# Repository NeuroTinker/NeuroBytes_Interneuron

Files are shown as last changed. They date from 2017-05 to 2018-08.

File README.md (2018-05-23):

# NeuroBytes Interneuron
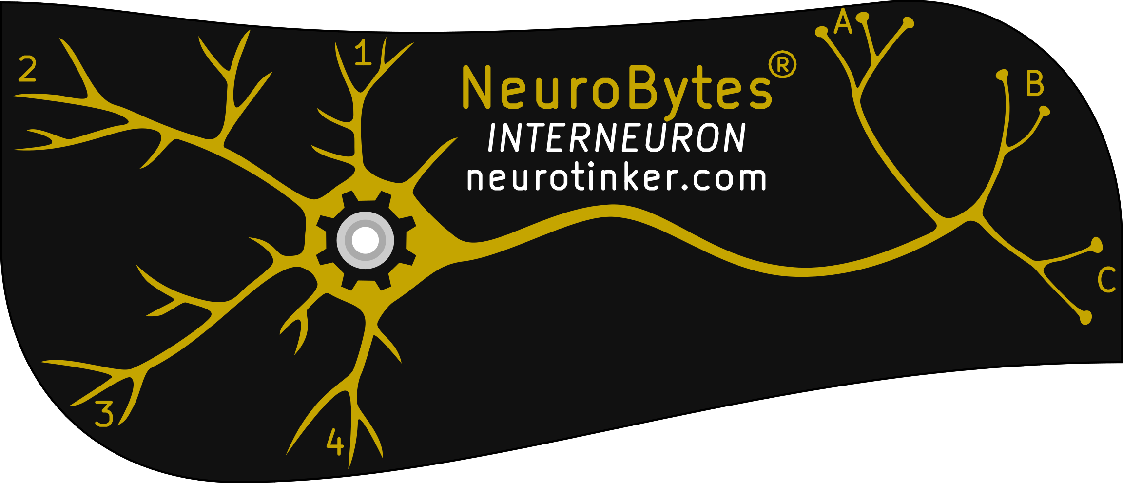
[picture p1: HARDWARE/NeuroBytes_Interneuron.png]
NeuroBytes Interneuron PCB front

The Interneuron is an open-source hardware neuron simulator designed and sold by [NeuroTinker, LLC](http://www.neurotinker.com/). Each device includes a number of inputs (dendrites) and outputs (the axon terminal) that can be freely connected to other NeuroBytes boards using 4-pin 'neurotransmitter' cables. Interneurons use a single RGB LED to indicate current status, and include a side-mounted push button for network identification. 

All NeuroBytes products are based on the ST32L0x series of ARM Cortex-M0+ 32-bit microcontrollers. The boards were designed in KiCad and Inkscape and are released under the terms of the Creative Commons Attribution-ShareAlike 4.0 license, available here: http://creativecommons.org/licenses/by-sa/4.0/. The NeuroBytes Interneuron is Certified Open Source Hardware as defined by [OSHWA](https://www.oshwa.org), certification number US000113.


OSHWA Certification

This repository is a continuation of the 8-bit ATtiny design called [NeuroBytes v0.91](https://github.com/zakqwy/neurobytes). The two series are not compatible.

## Project Status
This project is in alpha. The firmware is in progress and the API may change at any time. The PCB design is physically tested but has not yet been manufactured at scale.

## More Information
The NeuroBytes GitHub repositories store engineering information and make the design history of the project available to the public. Hardware- and firmware-specific README.md files can be found in their appropriate subdirectories. 

We encourage community involvement in our efforts, keeping in mind that hardware availability is currently quite limited. For product availability, operating guidelines, curricula, and information about NeuroTinker, LLC, head to neurotinker.com. Further technical logs are also at https://hackaday.io/project/3339-neurobytes.

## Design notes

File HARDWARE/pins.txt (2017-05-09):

NAME	PORT	PIN

D1EX	PB	1	
D1IN	PB	0
D2EX	PA	7
D2IN	PA	6
D3EX	PA	5
D3IN	PA	4
D4EX	PA	3	
D4IN	PA	2
	
A1EX	PA	8
A1IN	PC	15
A2EX	PB	4*
A2IN	PA	9
A3EX	PC	14
A3IN	PA	10

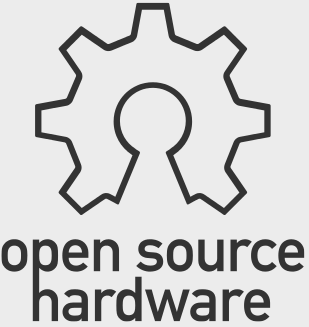
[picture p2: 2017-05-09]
HARDWARE/oshw.png

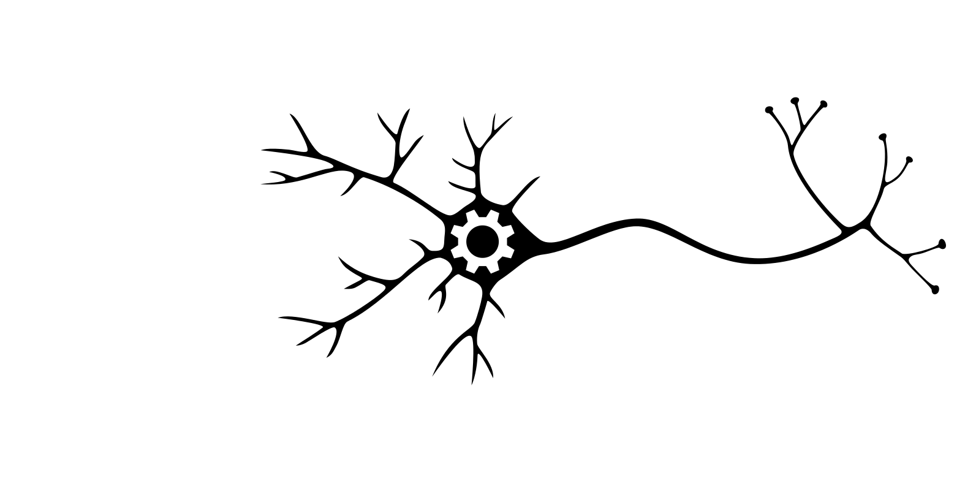
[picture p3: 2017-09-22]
HARDWARE/copper.png

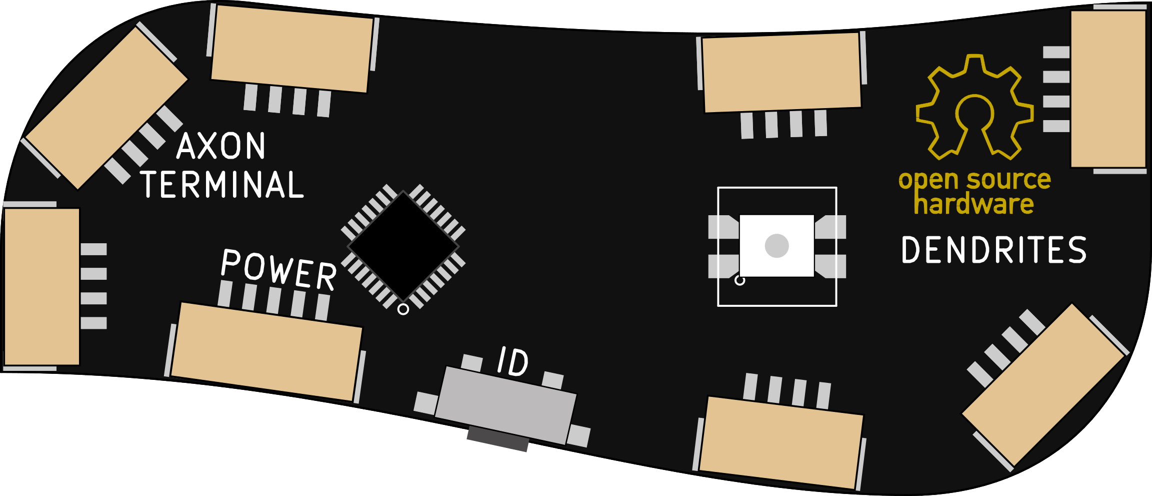
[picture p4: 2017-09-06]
HARDWARE/NeuroBytes_Interneuron_back.png

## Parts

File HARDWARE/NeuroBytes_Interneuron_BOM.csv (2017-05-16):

Title | NeuroBytes Interneuron
Revision | C
Date | 2017-05-15
Generated | Mon 15 May 2017 08:22:36 PM CDT
Company | NeuroTinker | LLC
Comment 1
Comment 2
Comment 3
Comment 4
Total Parts | 24
Total Unique Parts | 14
Ref | Qty | Value | Link | Mfr | Mfr Part # | Package | RoHS | Subs Allowed
C3 C5 | 2 | 100 nF | https://www.digikey.com/product-detail/en/taiyo-yuden/LMK105BJ104KV-F/587-1227-2-ND/930579 | Taiyo Yuden | LMK105BJ104KV-F | 0402 | Yes | No
C1 C4 | 2 | 1 uF | https://www.digikey.com/product-detail/en/taiyo-yuden/LMK107B7105KA-T/587-1242-2-ND/930594 | Taiyo Yuden | LMK107B7105KA-T | 0603 | Yes | Yes
C2 | 1 | 10 uF | https://www.digikey.com/product-detail/en/kemet/T491A106K010AT/399-3684-2-ND/818545 | Kemet | T491A106K010AT | 1206 | Yes | No
D1 | 1 | RGB LED CA | https://www.digikey.com/product-detail/en/sunled/XZMDKCBDDG45S-9/1497-1257-1-ND/5169746 | SunLED | XZMDKCBDDG45S-9 | 4-PLCC bottom mtg | Yes | No
P1 P6 P7 P2 P3 P4 P5 | 7 | JST GH 4-POS | N/A (NeuroTinker supplied) | JST | SM04B-GHS-GD-TB(LF)(SN) | SMT | Yes | No
P8 | 1 | JST GH 7-POS | https://www.digikey.com/product-detail/en/jst-sales-america-inc/SM07B-GHS-TB(LF)(SN)/455-1569-1-ND/807837 | JST | SM07B-GHS-TB(LF)(SN) | SMT | Yes | No
Q2 Q1 | 2 | NPN 3904 Dual | https://www.digikey.com/product-detail/en/on-semiconductor/MBT3904DW1T1G/MBT3904DW1T1GOSCT-ND/918012 | ON Semiconductor | MBT3904DW1T1G | SOT-363 | Yes | Yes
R1 | 1 | 150 | https://www.digikey.com/product-detail/en/yageo/RC0402FR-07150RL/311-150LRCT-ND/729490 | Yageo | RC0402FR-07150RL | 0402 | Yes | Yes
R2 R3 | 2 | 100 | https://www.digikey.com/product-detail/en/yageo/RC0402FR-07100RP/YAG1248CT-ND/4935363 | Yageo | RC0402FR-07100RP | 0402 | Yes | Yes
R4 | 1 | Jumper (0 ohm) | https://www.digikey.com/product-detail/en/yageo/RC0402JR-070RL/311-0.0JRTR-ND/726406 | Yageo | RC0402JR-070RL | 0402 | Yes | Yes
RN1 | 1 | 1k (x4) | https://www.digikey.com/product-detail/en/cts-resistor-products/741C083102JP/741C083102JPTR-ND/1124492 | CTS Resistor Products | 741C083103JP | 0804 | Yes | Yes
SW1 | 1 | SW_PUSH_TL3330AF130QG | https://www.digikey.com/product-detail/en/e-switch/TL3330AF130QG/EG4388CT-ND/1426858 | E-Switch | TL3330AF130QG | Gull Wing | Yes | No
U1 | 1 | STM32L011Gx | N/A (NeuroTinker supplied) | ST Microelectronics | STM32L011G4U6 | 28-UFQFN | Yes | No
U2 | 1 | LDO_LD3985M33R | https://www.digikey.com/product-detail/en/stmicroelectronics/LD3985M33R/497-3504-1-ND/669344 | ST Microelectronics | LD3985M33R | SOT-23-5 | Yes | No
BOM made with KICAD_BOM_WIZARD (https://github.com/HashDefineElectronics/KiCad_BOM_Wizard.git)
Generated Mon 15 May 2017 08:22:36 PM CDT

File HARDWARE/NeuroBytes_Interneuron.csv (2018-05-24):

Ref | Qty | Value | Link | Mfr | Mfr Part # | Package | RoHS | Subs Allowed
C3 C5 | 2 | 0u1 | https://www.digikey.com/product-detail/en/taiyo-yuden/LMK105BJ104KV-F/587-1227-2-ND/930579 | Taiyo Yuden | LMK105BJ104KV-F | C0402 | Yes | Yes
C1 C4 | 2 | 1u0 | https://www.digikey.com/product-detail/en/taiyo-yuden/LMK107B7105KA-T/587-1242-2-ND/930594 | Taiyo Yuden | LMK107B7105KA-T | C0603 | Yes | Yes
C2 | 1 | 10u | https://www.digikey.com/product-detail/en/taiyo-yuden/EMK316B7106KL-TD/587-2395-2-ND/2178914 | Taiyo Yuden | EMK316B7106KL-TD | C1206 | Yes | Yes
D1 | 1 | LED_RABG | https://www.digikey.com/product-detail/en/sunled/XZMDKCBDDG45S-9/1497-1257-2-ND/4902045 | SunLED | XZMDKCBDDG45S-9 | SMT | Yes | No
P1 P2 P3 P4 P5 P6 P7 | 7 | JST GH 4-POS | https://www.digikey.com/product-detail/en/jst-sales-america-inc/SM04B-GHS-TB-LF-SN/455-1566-2-ND/807788 | JST | SM04B-GHS-TB(LF)(SN)- | SMT | Yes | No
P8 | 1 | JST_GH_5-pos | https://www.digikey.com/product-detail/en/jst-sales-america-inc/SM05B-GHS-TB-LF-SN/455-1567-2-ND/807789 | JST | SM05B-GHS-TB(LF)(SN) | SMT | Yes | No
Q1 Q2 Q3 | 3 | MMBT3904 | https://www.digikey.com/product-detail/en/micro-commercial-co/MMBT3904-TP/MMBT3904TPMSTR-ND/717280 | Micro Commercial Co | MMBT3904-TP | SOT233 | Yes | Yes
R1 | 1 | 150 | https://www.digikey.com/product-detail/en/yageo/RC0402FR-07150RL/311-150LRCT-ND/729490 | Yageo | RC0402FR-07150RL | R0402 | Yes | Yes
R2 R3 | 2 | 100 | https://www.digikey.com/product-detail/en/yageo/RC0402FR-07100RL/311-100LRTR-ND/726527 | Yageo | RC0402FR-07100RL | R0402 | Yes | Yes
R4 | 1 | JMP | https://www.digikey.com/product-detail/en/yageo/RC0402JR-070RL/311-0.0JRTR-ND/726406 | Yageo | RC0402JR-070RL | R0402 | Yes | Yes
R5 R6 R7 | 3 | 1k | https://www.digikey.com/product-detail/en/yageo/RC0402FR-071KL/311-1.00KLRTR-ND/726513 | Yageo | RC0402FR-071KL | R0402 | Yes | Yes
SW1 | 1 | SW_PUSH_TL3330AF130QG | https://www.digikey.com/product-detail/en/e-switch/TL3330AF130QG/EG4388TR-ND/1426835 | E-Switch | TL3330AF130QG | SMT | Yes | No
U1 | 1 | STM32L011Gx | http://www.mouser.com/ProductDetail/STMicroelectronics/STM32L011G4U6/ | ST Microelectronics | STM32L011G4U6 | 28-UFQFN | Yes | No
U2 | 1 | TLV702 | https://www.digikey.com/product-detail/en/on-semiconductor/NCP114BSN330T1G/NCP114BSN330T1GOSTR-ND/6560606 | ON Semiconductor | NCP114BSN330T1G | SOT-23-5 | Yes | Yes
BOM made with KICAD_BOM_WIZARD (https://github.com/HashDefineElectronics/KiCad_BOM_Wizard.git)
Generated Wed 23 May 2018 02:46:01 PM CDT

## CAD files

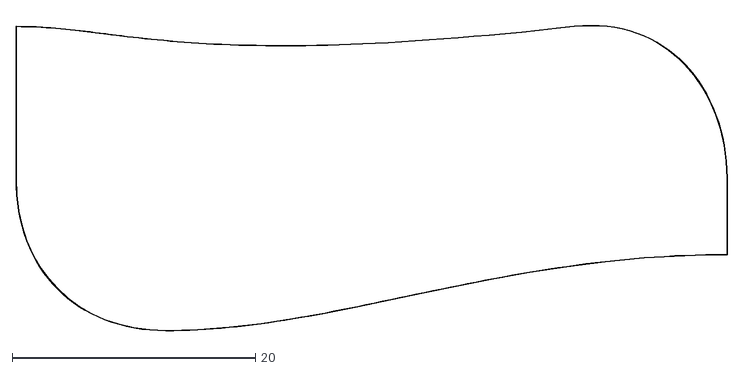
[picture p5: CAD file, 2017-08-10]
HARDWARE/NeuroBytes_Interneuron.dxf
58.4 x 25.8

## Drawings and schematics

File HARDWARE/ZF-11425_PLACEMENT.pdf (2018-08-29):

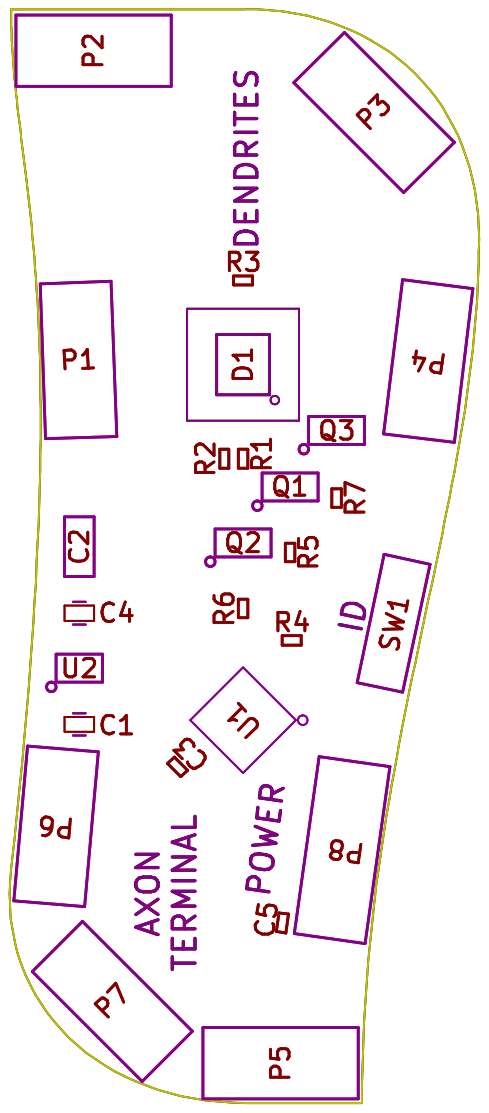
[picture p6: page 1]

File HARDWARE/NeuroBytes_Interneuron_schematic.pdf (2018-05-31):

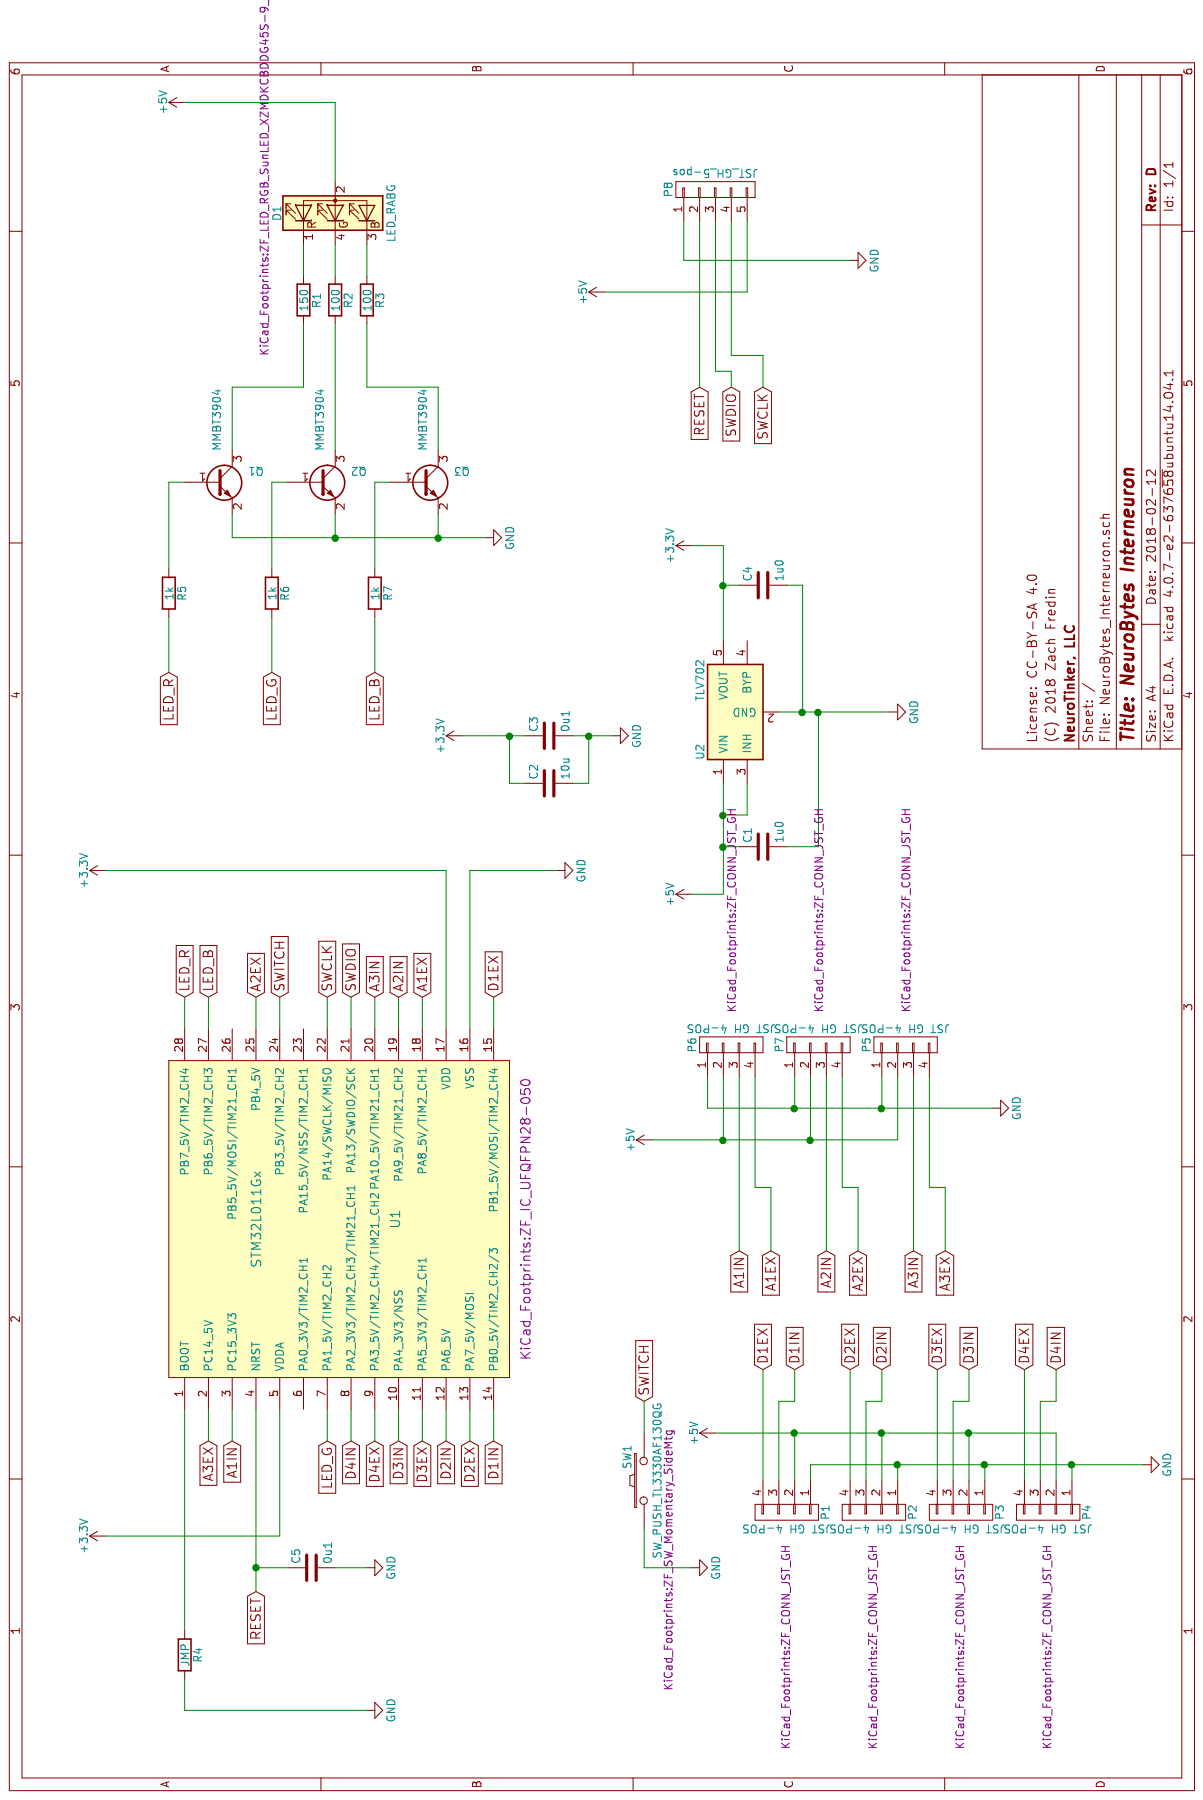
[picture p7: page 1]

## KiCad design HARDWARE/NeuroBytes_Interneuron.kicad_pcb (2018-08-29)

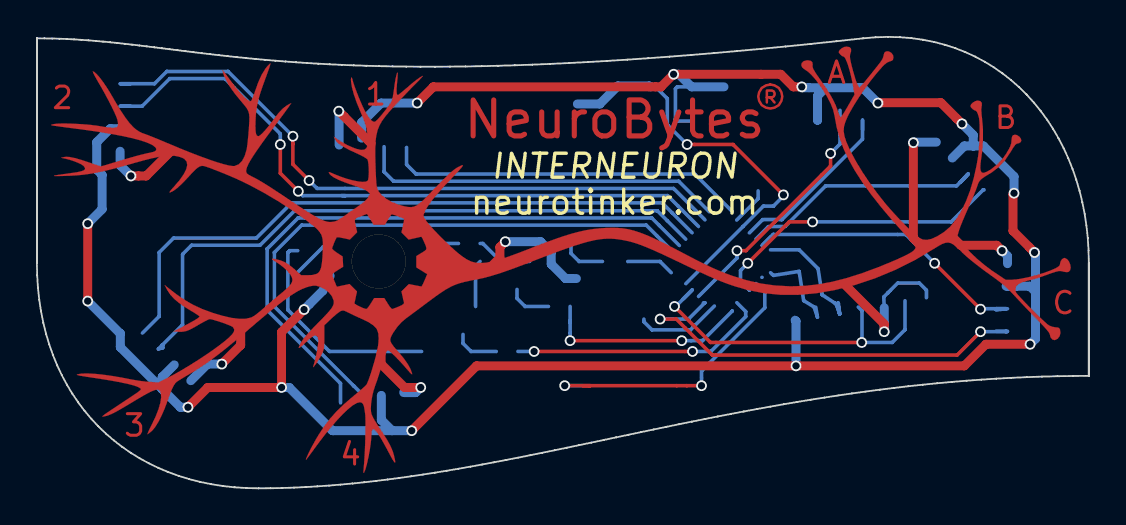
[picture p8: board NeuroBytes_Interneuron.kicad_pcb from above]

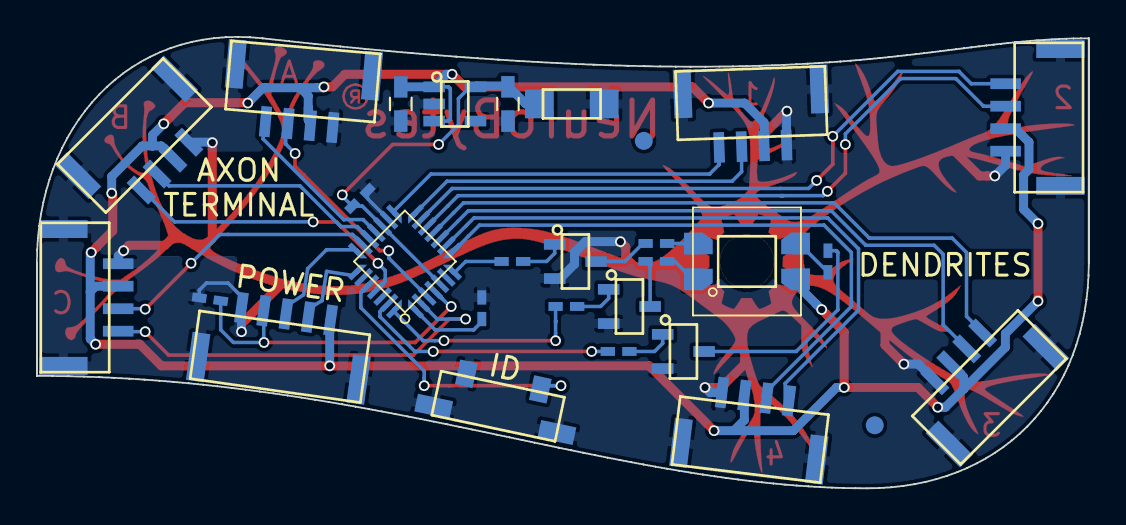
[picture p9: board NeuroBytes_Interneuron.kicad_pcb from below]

Board: 2 copper layers, 58.4 x 25.1 mm, 27 parts (27 on the bottom side), 34 nets.

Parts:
C1, C4: 1u0; C_0603_HandSoldering
C2: 10u; ZF_SMD_nonpol_1206
C3, C5: 0u1; ZF_SMD_NonPol_0402_cap
D1: LED_RABG; ZF_LED_RGB_SunLED_XZMDKCBDDG45S-9_cast
P1, P2, P3, P4, P5, P6, P7: JST GH 4-POS; ZF_CONN_JST_GH
P8: JST_GH_5-pos; ZF_CONN_JST_GH_5POS
Q1, Q2, Q3: MMBT3904; ZF_SOT23-3L
R1: 150; ZF_SMD_NonPol_0402
R2, R3: 100; ZF_SMD_NonPol_0402
R4: JMP; ZF_SMD_NonPol_0402
R5, R6, R7: 1k; ZF_SMD_NonPol_0402
SW1: SW_PUSH_TL3330AF130QG; ZF_SW_Momentary_SideMtg
U1: STM32L011Gx; ZF_IC_UFQFPN28-050
U2: TLV702; ZF_SOT23-5L

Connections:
+3V3: C2.1, C3.1, C4.1, U1.5, U1.17, U2.5
+5V: C1.1, D1.2, P1.2, P2.2, P3.2, P4.2, P5.2, P6.2, P7.2, P8.5, U2.1, U2.3
A1EX: P6.4, U1.18
A1IN: P6.3, U1.3
A2EX: P7.4, U1.25
A2IN: P7.3, U1.19
A3EX: P5.4, U1.2
A3IN: P5.3, U1.20
D1EX: P1.4, U1.15
D1IN: P1.3, U1.14
D2EX: P2.4, U1.13
D2IN: P2.3, U1.12
D3EX: P3.4, U1.11
D3IN: P3.3, U1.10
D4EX: P4.4, U1.9
D4IN: P4.3, U1.8
GND: C1.2, C2.2, C3.2, C4.2, C5.2, P1.1, P2.1, P3.1, P4.1, P5.1, P6.1, P7.1, P8.1, Q1.2, Q2.2, Q3.2, R4.2, SW1.1, U1.16, U2.2
LED_B: R7.2, U1.27
LED_G: R6.2, U1.7
LED_R: R5.2, U1.28
unnamed: D1.1, R1.1
unnamed: D1.3, R3.1
unnamed: D1.4, R2.1
unnamed: Q1.1, R5.1
unnamed: Q1.3, R1.2
unnamed: Q2.1, R6.1
unnamed: Q2.3, R2.2
unnamed: Q3.1, R7.1
unnamed: Q3.3, R3.2
unnamed: R4.1, U1.1
RESET: C5.1, P8.2, U1.4
SWCLK: P8.4, U1.22
SWDIO: P8.3, U1.21
SWITCH: SW1.2, U1.24

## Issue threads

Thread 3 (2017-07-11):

Simultaneous inputs don't sum

zakqwy, 2017-07-11:
Action potentials received on dendrites 2 and 3 at the exact same time (i.e. from the same Touch Sensor) don't sum and cause an action potential.

jrwhite, 2017-09-07:
Memory mode is now present on the latest release.

jrwhite, 2017-09-11:
This bug has been fixed in the latest 'development' commit but I'll leave this issue open until the fix is merged to 'master'.

After playing around with this issue, I found that the axon signal that slightly led the other axon signal (usually by about 0.5 microseconds) always received by the dendrite but the lagging axon's message was always dropped.
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

In this capture,  the top trace is Axon 1 and the bottom trace is Axon 2. Axon 2 always sends its message with a slight delay to Axon 1 and appears to never trigger the incoming message interrupt on the target dendrite. This leads me to believe that once the GPIO external interrupt which starts the message reading sequence (EXTI) is triggered, no more EXTIs can be queued until the EXTI routine has finished. So far, I haven't found anything in the NVIC settings that would prohibit another EXTI from being queued so I'm guessing that multiple EXTIs can't be queued on the STM32L0. The EXTI routine processing time is just a few microseconds so I've added a small 100 microsecond delay between simultaneous axon messages so that the receiving NeuroBytes board has enough time to process the first EXTI before receiving the second.

This issue affects all NeuroBytes boards with axons (i.e. everything but the motor neuron) so I've pushed fixes to all repos' 'development' branches.

Closed 2017-09-22.

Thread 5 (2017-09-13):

memory mode improvements

zakqwy, 2017-09-13:
Test out depression to balance potentiation. Try with LED staying magenta in memory mode and at a relatively low brightness. An action potential leads to a magenta flash instead of white. As a synapse is potentiated, the magenta LED brightness increases to some max value. When inputs stop, depression begins, and the magenta LED brightness reduces back to baseline over the course of let's say 10 seconds for now.

zakqwy, 2017-09-26:
Joe is testing this in classrooms this week (end of September). Will close upon confirmation of goodness.

zakqwy, 2017-10-03:
New changes requested -- see Slack Products discussion 10/2/2017 for detail. briefly, eliminate depression and focus on associativity. if an Interneuron is firing at >1 Hz, any excitatory signals to sub-threshold dendrites should cause increases in weighting.

Closed 2018-12-29.

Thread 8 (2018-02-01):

Temporal Summation

NeuroTinkerJoe, 2018-02-01:
Weighting of #4 short dendrite is less than weighting of #1 short dendrite. An incoming AP on #1 always leads to firing, whereas two APs in quick succession are needed on #4 to fire an AP.

The weighting of dendrites #2 and #3 seems to be too low, APs can not be fired even with rapid signals coming into these dendrites.

In addition, the LED color change from green to yellow with a subthreshold increase in membrane potential is difficult to see, it looks more like a flickering of the green LED.

Closed 2018-12-29.

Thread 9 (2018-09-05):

Increase action potential flash brightness

zakqwy, 2018-09-05:
Try a few different brightness increases to make the A.P. flash more apparent. The current level is too dim. Once this is determined, extend similar scheme to other NeuroBytes that use RGB indication.

jrwhite, 2018-12-29:
Fixed

Closed 2018-12-29.

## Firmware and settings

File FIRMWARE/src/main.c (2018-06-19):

#include <libopencm3/stm32/rcc.h>
#include <libopencm3/stm32/gpio.h>
#include <libopencm3/stm32/timer.h>
#include <libopencm3/cm3/nvic.h>
#include <libopencm3/cm3/systick.h>
#include <libopencm3/stm32/exti.h>
#include <libopencm3/stm32/usart.h>

#include "HAL.h"
#include "comm.h"
#include "neuron.h"

// #define DBG

#define BLINK_TIME			40
#define DATA_TIME			10
#define DEND_PING_TIME		200 // 1000 ms
#define	NID_PING_TIME		200 // 1000 ms
#define SEND_PING_TIME		80 // 80
#define BUTTON_PRESS_TIME	2
#define BUTTON_HOLD_TIME    100
#define LPUART_SETUP_TIME	100
#define CHANGE_NID_TIME 	200
#define HEBB_LEARNING_DELAY 1000

#define _learning_brightness
#define _learning_led (pot, joe) (setLED())

#define	MAX_ZACHNESS		64
#define MIN_ZACHNESS		32

typedef enum {
	BLINK	=	0b0000,
	PAUSE	=	0b0001
} command_id;

typedef enum{
	DECAY 		=	0b0000,
    DEND1       =   0b0001,
    DEND2       =   0b0010,
    DEND3       =   0b0011,
	DEND4       =   0b0100,
	THRESHOLD 	=	0b0101,
	DEPRESSION	=	0b0111,
	LWINDOW		=	0b1000,
	DELAY		=	0b1101
} parameter_identifiers;

int main(void)
{
	uint8_t		i;

	// counters
	uint32_t	blink_time = 0; // counter for LED blink due to NID command
	uint16_t	data_time = 0; // counter for sending data to NID
	uint16_t	send_ping_time = 0; // counter for sending a downstream ping
	uint16_t	fire_delay_time = 0;
	int16_t 	depression_time = 0;
	uint8_t		fire_flag = 0;
	uint16_t	lpuart_setup_time = 0;
	uint8_t		change_nid_time = 0;
	int16_t		fire_data = 0; // hack to make sure a pulse sends peak neuron potential and hyperpolarization  data
	uint16_t	fire_delay_time_reset = FIRE_DELAY_TIME;
	fire_delay_time_reset = 40; // temporary
	uint16_t	fire_delay_overflow = 0; // used if firing period is less than delay time.

	// button debounce variables
	uint16_t	button_press_time = 0; 
	uint8_t		button_armed = 0;
	uint16_t	button_status = 0;

	uint8_t		decay_delay_time = 0;
	uint8_t		DECAY_DELAY_TIME = 1;

	int32_t		threshold_potential = MEMBRANE_THRESHOLD;
	message_t	message; // for constructing messages to send to the communications routine

	int32_t joegenta = 0;
	int32_t zachness = 0;
	int32_t blue = 0;
	int32_t red = 0;
	uint32_t hebb_learning_delay = 0;

	// initialize neuron
	neuron_t 	neuron;
	neuronInit(&neuron);

	neuron.dendrites[0].magnitude = 15000;
	neuron.dendrites[1].magnitude = 7000;
	neuron.dendrites[2].magnitude = 7000;
	neuron.dendrites[3].magnitude = 11000;

	neuron.dendrites[0].base_magnitude = 15000;
	neuron.dendrites[1].base_magnitude = 7000;
	neuron.dendrites[2].base_magnitude = 7000;
	neuron.dendrites[3].base_magnitude = 11000;

	// initialize communication buffers
	commInit();

	// setup hardware
	clock_setup();
	systick_setup(); // systick in microseconds
	gpio_setup();
	tim_setup();

	#ifdef DBG
	blink_flag = 1;
	#endif

	// main processing routine	
	for(;;)
	{
		if (main_tick == 1 && pause_flag == 0){
			// main tick every 5 ms
			main_tick = 0;
			// check to see if nid ping hasn't been received in last NID_PING_TIME ticks
			if (nid_ping_time > 0){
				nid_ping_time -= 1;
				if (nid_ping_time == 0){
					// nid no longer connected
					nid_distance = 100; // reset nid_keep_alive
					nid_pin = 0; // clear the nid pin
					nid_pin_out = 0;
					nid_i = NO_NID_I;
				}
			}

			if (change_nid_time++ > CHANGE_NID_TIME){
				change_nid_time = 0;
				closer_distance = nid_distance;
				closer_ping_count = 0;
			}
			
			// send a downstream ping every SEND_PING_TIME ticks
			if (send_ping_time++ > SEND_PING_TIME){
				// send downstream ping through axon
				addWrite(DOWNSTREAM_BUFF, downstream_ping_message);
				send_ping_time = 0;
			}

			if (lpuart_setup_time < LPUART_SETUP_TIME){
				lpuart_setup_time += 1;
			} else if (lpuart_setup_time == LPUART_SETUP_TIME){
				lpuart_setup_time += 1;
				#ifndef DBG
				lpuart_setup();
				#endif
			}

			/*
				Check to see if any comms flags have been set.
				Process any data that came from the NID.
			*/

			if (comms_flag != 0){
				switch (comms_flag){
					case DECAY:
						DECAY_DELAY_TIME = comms_data;
					case DEND1:
						neuron.dendrites[0].magnitude = comms_data;
						break;
					case DEND2:
						neuron.dendrites[1].magnitude = comms_data;
						break;
					case DEND3:
						neuron.dendrites[2].magnitude = comms_data;
						break;
					case DEND4:
						neuron.dendrites[3].magnitude = comms_data;
						break;
					case THRESHOLD:
						threshold_potential = comms_data;
					case DELAY:
						fire_delay_time_reset = comms_data;
					default:
						break;
				}
				comms_flag = 0;
				comms_data = 0;
			}

			/*
				nid_channel is the current channel, if any, that the NeuroByte is using to communicate
				with the NID. nid_channel should be cleared when NID tries to set a new NeuroByte to 
				identify_channel.

				The communication routine sets identify_time to zero when a new identify command is received.
			*/

			// check for clear channel command
			if (identify_time < IDENTIFY_TIME){
				if (identify_time == 0){
					if ((identify_channel == 0) || (identify_channel == nid_channel)){
						nid_channel = 0;
					}
				}
				identify_time += 1;
			}

			// check identify button
			button_status = gpio_get(PORT_IDENTIFY, PIN_IDENTIFY);

			// if identify button is pressed and identify_time < IDENTIFY_TIME (i.e. NID sent 'identify'' message), set new nid_channel
			if (button_status == 0){
				// debounce
				button_press_time += 1;
				if (button_press_time >= BUTTON_HOLD_TIME){
					button_armed = 2;
					blink_flag = 1;
				} else if (button_press_time >= BUTTON_PRESS_TIME){
					button_armed = 1;
				}
			} else{
				// button not pressed
				if (button_armed == 0){
					button_press_time = 0;
				} else if (button_armed == 1 && nid_i != NO_NID_I){
					nid_channel = identify_channel;
					message.length = 32;
					message.message = (((uint32_t) DATA_TYPE_MESSAGE) | (((uint32_t) nid_channel) << 22));
					message.message |=  ((const uint16_t) (getFingerprint()));
					addWrite(NID_BUFF, (const message_t) message);
					identify_time = 1;
					button_armed = 0;
				} else if (button_armed == 2){
					if (neuron.learning_state == NONE){
						neuron.learning_state = HEBB;
					} else if (neuron.learning_state == HEBB){
						neuron.learning_state = NONE;
					}
					button_armed = 0;
				}
				button_press_time = 0;
			}
						
			/*
				Check dendrites for pings and adjut pins accordingly.
				Also check dendrites for pulses and calculate new membrane potential.
			*/
			checkDendrites(&neuron);
			
			// decay old dendrite contributions to the membrane potential
			if (++decay_delay_time >= DECAY_DELAY_TIME){
				decay_delay_time = 0;
				dendriteDecayStep(&neuron);
			}
			// decay the firing potential
			membraneDecayStep(&neuron);

			// current membrane potential comes from dendrites and any left over firing potential
			neuron.potential = calcNeuronPotential(&neuron);
			neuron.potential += neuron.fire_potential;
			neuron.fire_potential += neuron.leaky_current;

			// send current membrane potential to NID if currently identified by NID
			if (nid_channel != 0){
				// send data every DATA_TIME ticks
				if (data_time++ > DATA_TIME){
					if (fire_data > 0){
						if (fire_data == 1){
							message.message = (((uint32_t) DATA_MESSAGE)) | ((uint16_t) HYPERPOLARIZATION);
							fire_data = 0;						
						} else {
							message.message = (((uint32_t) DATA_MESSAGE)) | ((uint16_t) fire_data);	
							fire_data = 1;						
						}
					} else {
						message.message = (((uint32_t) DATA_MESSAGE)) | ((uint16_t) neuron.potential);						
					}
					data_time = 0;
					message.length = 32;
					message.message |= (nid_channel << 22);
					addWrite(NID_BUFF,(const message_t) message);
				}
			}

			// if membrane potential is greater than threshold, fire
			if (neuron.potential > MEMBRANE_THRESHOLD){
				// fire for determined pulse width
				neuron.state = FIRE;
				neuron.fire_potential = HYPERPOLARIZATION;
				neuron.fire_time = PULSE_LENGTH;
				for (i=0; i<NUM_DENDS; i++){
					neuron.dendrites[i].current_value = 0;
					neuron.dendrites[i].state = OFF;
					// if (neuron.learning_state == HEBB){
					// 	calcDendriteWeightings(&neuron);
					// }
				}
				if (neuron.learning_state == HEBB){
					calcDendriteWeightings(&neuron);
					hebb_learning_delay = 0;
				}
				depression_time = 0;

				fire_data = neuron.potential; // hack to send fire data to NID

				// send downstream pulse
				if (fire_delay_time == 0){
					fire_delay_time = fire_delay_time_reset;
					fire_delay_overflow = 0;
				} else {
					fire_delay_overflow = fire_delay_time_reset - fire_delay_time;
				}
				fire_flag = 1;
			} else if (neuron.potential < HYPERPOLARIZATION){
				neuron.potential = HYPERPOLARIZATION;
			}

			if (fire_delay_time > 0){
				fire_delay_time -= 1;
			} else if (fire_flag == 1){
				if (fire_delay_overflow > 0)
					fire_delay_time = fire_delay_overflow; // TODO: make this an actual FIFO buffer of fire timings
				fire_flag = 0;
				addWrite(DOWNSTREAM_BUFF, pulse_message);
			}
			
			if ((neuron.learning_state == HEBB) && (hebb_learning_delay++ >= HEBB_LEARNING_DELAY)){
				hebb_learning_delay = hebb_learning_delay >= HEBB_LEARNING_DELAY ? HEBB_LEARNING_DELAY : hebb_learning_delay;
				if (++depression_time >= DEPRESSION_TIME){
					for (i=0; i<NUM_DENDS; i++){
						neuron.dendrites[i].magnitude -= neuron.dendrites[i].base_magnitude;
						neuron.dendrites[i].magnitude *= 511;
						neuron.dendrites[i].magnitude /= 512;
						neuron.dendrites[i].magnitude += neuron.dendrites[i].base_magnitude;
					}
				}		
			}	
			joegenta = 0;
			for (i=0; i<NUM_DENDS; i++){
				joegenta += neuron.dendrites[i].magnitude - neuron.dendrites[i].base_magnitude;
			}
			

			/*
				LED is either:
				-blinking due to NID message (blink_flag is set)
				-full white if neuron is firing
				-in an RGB state mapped to membrane potential
			*/
			if (blink_flag != 0){
				setLED(200,0,300);
				blink_time = 1;
				blink_flag = 0;
			} else if (blink_time > 0){
				if (++blink_time == BLINK_TIME){
					setLED(200,0,200);
					blink_time = 0;
				}
			} else if (neuron.state == FIRE){
				neuron.fire_time -= 1;
				if (neuron.fire_time == 0){
					neuron.state = INTEGRATE;
				}
				if (neuron.learning_state == HEBB){
					// needs to vary between 50 and 320
					joegenta /= 256;
					joegenta *= 3;
					joegenta += 100;
					if (joegenta > 350) joegenta = 350;
					setLED(joegenta, joegenta, joegenta);
				} else{
					LEDFullWhite();
				}
			} else if (neuron.state == INTEGRATE){
				if (neuron.learning_state == HEBB){
					if (neuron.potential > 10000) {
						red = 200;
						blue = 0;
						// max magenta
					} else if (neuron.potential < -10000) {
						// min brightness
						red = 0;
						blue = 200;
					} else if (neuron.potential < 0) {
						// temp min brightness
						red = 100 + (neuron.potential / 100);
						blue = 100 - (neuron.potential / 100);
					} else if (neuron.potential > 0) {
						// calculate
						red = 100 + (neuron.potential / 100);
						blue = 100 - (neuron.potential / 100);
					} else {
						red = 100;
						blue = 100;
					}

					joegenta /= 256; // up to 187
					if (joegenta < 120) {
						red *= (joegenta + 20);
						red /= 40;
						blue *= (joegenta + 20);
						blue /= 40;
					} else {
						red *= 130;
						red /= 40;
						blue *= 130;
						blue /= 40;
					}
					if (red > 300) red = 300;
					if (blue > 300) blue = 300;
					setLED(red, 0, blue);

				} else{
					if (neuron.potential > 10000){
						setLED(200,0,0);
					} else if (neuron.potential > 0){
						setLED(neuron.potential / 50, 200 - (neuron.potential / 50), 0);
					} else if (neuron.potential < -10000){
						setLED(0,0, 200);
					} else if (neuron.potential < 0){
						setLED(0, 200 + (neuron.potential / 50), -1 * neuron.potential / 50);
					} else{
						setLED(0,200,0);
					}
				}
			}
		}
	}
}

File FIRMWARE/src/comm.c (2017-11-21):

#include "comm.h"
#include "HAL.h"

write_buffer_t write_buffer;
read_buffer_t read_buffer[NUM_INPUTS] = {
    [0 ... MAX_I] = { .message=0, .bits_left_to_read=4, .callback=processMessageHeader}
}; // fast 'gcc' way to initialize the whole array of read_buffer_t struct

volatile uint8_t blink_flag = 0;
volatile uint32_t nid_ping_time = 0;
volatile uint16_t nid_pin = 0;
uint32_t nid_port = 0;
volatile uint16_t nid_pin_out = 0;
uint32_t nid_port_out = 0;
uint8_t nid_i      =    13;
volatile uint8_t  nid_distance = 100; // max uint8_t
volatile uint8_t closer_ping_count = 0;
volatile uint8_t closer_distance = 100;

const message_t pulse_message = {.length=4, .message=PULSE_HEADER};
const message_t downstream_ping_message = {.length=4, .message=DOWNSTREAM_PING_HEADER};
const message_t blink_message = {.length=4, .message=BLINK_HEADER};

uint8_t write_count = 0;
volatile uint16_t identify_time = IDENTIFY_TIME;
uint8_t identify_channel = 0;

void commInit(void)
{
    uint8_t i;
    for (i=0;i<NUM_INPUTS;i++) read_buffer[i].i = i;
    write_buffer.current_buffer = NONE_BUFF;
    write_buffer.write_count = 0;
    write_buffer.num_bits_to_write = 1;
}

void readBit(uint8_t read_tick)
{
    uint8_t i;
    uint16_t value;

    for (i=0; i<NUM_INPUTS; i++){
        // read each input that is currently receiving a message
        if ((active_input_pins[i] != 0) && (active_input_tick[i] == read_tick)){

            // get new input value
            value = gpio_get(active_input_ports[i], active_input_pins[i]); // returns uint16 where bit position corresponds to pin number
            if (value != 0){
                value = 1;
            } else{
                value = 0;
            }

            // save new input value to buffer
            read_buffer[i].message <<= 1;
            read_buffer[i].message |= value;

            // if enough bits have been read from the message to process, then trigger callback

            if (--read_buffer[i].bits_left_to_read == 0){ // done reading message
                // execute message callback. returns true if there is more to be read
                if (!read_buffer[i].callback(&read_buffer[i])){
                     // deactivate input so that it doesn't keep getting read
                    EXTI_PR |= active_input_pins[i];
                    exti_enable_request(active_input_pins[i]);
                    active_input_pins[i] = 0;
                    // reset message buffer
                    read_buffer[i].message = 0;
                    read_buffer[i].bits_left_to_read = 4;
                    read_buffer[i].callback = processMessageHeader;
                }
            }
        }
    }
}

bool processMessageHeader(read_buffer_t * read_buffer_ptr)
{
    uint8_t i = read_buffer_ptr->i;
    uint8_t header = read_buffer_ptr->message & 0b1111;

    switch (header){
        case PULSE_HEADER:
            dendrite_pulse_flag[i] = 1;
            break;
        case DOWNSTREAM_PING_HEADER:
            /* Check to make sure it's a dendrite */
            if (i >= NUM_AXONS){
                dendrite_ping_flag[i] = 1;
                setAsOutput(complimentary_ports[i], complimentary_pins[i]);
                active_output_pins[COMPLIMENTARY_I(i)] = complimentary_pins[i];
                active_output_pins[i] = 0; // might not be neccesary
            }
            break;
        case BLINK_HEADER:
            if ((blink_flag == 0) && (i == nid_i)){
                // set blink_flag => main() will blink led
                blink_flag = 1;
                // forward message through network
                addWrite(ALL_BUFF, blink_message);
                write_buffer.source_pin = i;
            }
            break;
        case NID_PING_HEADER:
            // NID ping received. Read the distance packet and then process it.
            read_buffer_ptr->bits_left_to_read = 6;
            read_buffer_ptr->callback = processNIDPing;
            return true;
            break;
        case NID_GLOBAL_HEADER:
            if (i == nid_i){
                read_buffer_ptr->bits_left_to_read = 6;
                read_buffer_ptr->callback = processGlobalCommand;
                return true;
            }
            break;
        case DATA_HEADER:
            read_buffer_ptr->bits_left_to_read = 28;
            read_buffer_ptr->callback = processDataMessage;
            return true;
            break;
        default:
            break;
    }
    return false;
}

bool processDataMessage(read_buffer_t * read_buffer_ptr)
{
    const message_t frwd_message = {.length=32, .message=read_buffer_ptr->message};
    addWrite(NID_BUFF, frwd_message);
    return false;
}

bool processGlobalCommand(read_buffer_t * read_buffer_ptr)
{
    uint8_t command = read_buffer_ptr->message & 0b111111;

    switch (command){
        case IDENTIFY_COMMAND:
            read_buffer_ptr->bits_left_to_read = 3;
            read_buffer_ptr->callback = processIdentifyCommand;
            return true;
            break;
        default:
            break;
    }
    const message_t frwd_message = {.length=10, .message=read_buffer_ptr->message};
    addWrite(ALL_BUFF, frwd_message);
    return false;
}

bool processIdentifyCommand(read_buffer_t * read_buffer_ptr)
{
    identify_channel = read_buffer_ptr->message & 0b111;
    identify_time = 0;
    const message_t frwd_message = {.length=13, .message=read_buffer_ptr->message};
    addWrite(ALL_BUFF, frwd_message);
    return false;
}
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

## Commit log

2017-03-16 Initial commit. Implemented libopencm3 as a git submodule following instructions from libopencm3-examples. Note that stm32l0xx4.ld was added to /libopencm3/lib/stm32/l0 (still in testing). Actual Neu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
2017-03-17 Got rid of helloworld test program and replaced with a basic hardware abstraction library and main code. Configurable for LED PWM testing on both the Motor Neuron and NeuroBytes v1.01 PCB designs (wh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
    [HAL.c, HAL.h, main.c]
2017-05-09 Initial hardware design files upload.
    [NeuroBytes_Interneuron-B.Cu.gbr, NeuroBytes_Interneuron-B.Mask.gbr, NeuroBytes_Interneuron-B.SilkS.gbr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]
2017-05-12 fixed dropped packet issue
    [HAL.c, HAL.h, comm.c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]
2017-05-15 added schematic library submodule
2017-05-15 Updated project file to include schematic library submodule
2017-05-16 Added PCB mfr notes on FAB layer. Modified QFN28 footprint to comply with IPC-7351FC Level B.
    [NeuroBytes_Interneuron.kicad_pcb, NeuroBytes_Interneuron.sch]
2017-05-16 Generated Gerber files, drill file, BOM, and placement file. Changed 7-pin JST connector designator to P8 (was P12, and P9-P11 don't exist).
    [NeuroBytes_Interneuron-B.Cu.gbr, NeuroBytes_Interneuron-B.Mask.gbr, NeuroBytes_Interneuron-B.Paste.gbr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]
2017-05-16 Cleaned up old Gerber files (that weren't in the HARDWARE/gerbers directory). Minor PCB updates.
    [NeuroBytes_Interneuron-B.Cu.gbr, NeuroBytes_Interneuron-B.Mask.gbr, NeuroBytes_Interneuron-B.SilkS.gbr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]
2017-05-16 Added license to schematic and layout title blocks. Updated BOM file name.
    [NeuroBytes_Interneuron.kicad_pcb, NeuroBytes_Interneuron.sch, NeuroBytes_Interneuron_BOM.csv]
2017-05-16 Updated Gerbers directory because 'Gerbers' should be capitalized. Thanks, Joseph Gerber.
    [NeuroBytes_Interneuron-B.Cu.gbr, NeuroBytes_Interneuron-B.Mask.gbr, NeuroBytes_Interneuron-B.Paste.gbr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]
2017-05-26 added leaky current
2017-05-31 Updated switch footprint (centered, removed part of support pad). Updated JST footprints (centered). BOM changes to reduce mfr cost: dual --> single NPN transistors; resistor network --> discrete res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
    [NeuroBytes_Interneuron.csv, NeuroBytes_Interneuron.kicad_pcb, NeuroBytes_Interneuron.sch]
2017-06-27 fixed memory segmentation bug
    [HAL.c, comm.c, main.c]
2017-07-25 added device id
2017-07-25 added fingerprint
2017-08-08 updated fingerprint
2017-08-09 Updated PCB outline to eliminate rotational symmetry. Changed to 5-pin JST GH connector for power. Numerous routing changes and minor graphics updates.
    [NeuroBytes_Interneuron.dxf, NeuroBytes_Interneuron.kicad_pcb, NeuroBytes_Interneuron.sch]
2017-08-10 added fingerprint elf offset
2017-08-11 changed fingerprint
2017-08-28 updated graphics to include kicad fonts. added png export of board front render.
2017-08-31 moved transistors around a bit so they don't overlap anymore.
    [NeuroBytes_Interneuron.kicad_pcb]
2017-08-31 changed comm interrupt to systick
2017-08-31 changed comms interrupt to systick
2017-09-11 fixed simultaneous excitation issue
    [comm.c]
2017-09-18 recalculated gamma correction table and changed ledFullWhite to reduce resting and A.P. brightness
    [HAL.c]
2017-09-21 updated Gerber fab layer notes. Mostly doing this to test slack integration.
    [NeuroBytes_Interneuron.kicad_pcb]
2017-09-21 updated BOM. removed old Gerber files. changed PCB art to use updated gear. pulled back mask on dendrite/axon labels. other minor changes.
    [NeuroBytes_Interneuron-B.Cu.gbr, NeuroBytes_Interneuron-B.Mask.gbr, NeuroBytes_Interneuron-B.Paste.gbr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]
2017-09-21 minor BOM updates
    [NeuroBytes_Interneuron.csv, NeuroBytes_Interneuron.sch]
2017-09-21 removed merge expressions preventing 'make'
    [HAL.c]
2017-09-22 minor updates to PCB. updated netlist.
    [NeuroBytes_Interneuron.kicad_pcb]
2017-10-03 minor title block and page layout changes
    [NeuroBytes_Interneuron.kicad_pcb, NeuroBytes_Interneuron.sch]
2017-10-06 updated LED brightness
2017-11-02 fixed axon 1 issue
    [HAL.c, HAL.h, comm.c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]
2017-11-08 comm and neuron abstraction. fixed write time
    [HAL.c, comm.c, main.c]
2017-11-21 moved fingerprint to HAL for... reasons...
2017-11-21 debugging weird LED issue
    [HAL.c, main.c]
2017-11-21 reenabled TIM2 isr. wierd fix.
    [HAL.c]
2017-11-29 fix bug where data transmits after NID disconnect
    [main.c]
2017-11-29 updated license and readme to CC-BY-SA 4.0. added drawing number to PCB layout.
    [NeuroBytes_Interneuron.kicad_pcb]
2018-02-13 added ESD protection. updated title block.
    [NeuroBytes_Interneuron.kicad_pcb, NeuroBytes_Interneuron.sch]
2018-03-08 minor PCB render updates
2018-05-23 removed ESD protection (not needed during testing). generated fab files and BOM.
    [NeuroBytes_Interneuron-B.Cu.gbr, NeuroBytes_Interneuron-B.Mask.gbr, NeuroBytes_Interneuron-B.Paste.gbr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]
2018-05-23 updated INSERT attribute. regenerated *.pos file.
    [NeuroBytes_Interneuron.kicad_pcb]
2018-05-31 added schematic *.pdf
2018-08-08 updated footprints to include B.Fab outlines. minor routing changes. re-generated Gerbers. added placement pdf.
    [NeuroBytes_Interneuron-B.Cu.gbr, NeuroBytes_Interneuron-B.Fab.gbr, NeuroBytes_Interneuron-B.Mask.gbr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]
2018-08-08 regen drill file
    [NeuroBytes_Interneuron.drl]
2018-12-29 increased LED brightness

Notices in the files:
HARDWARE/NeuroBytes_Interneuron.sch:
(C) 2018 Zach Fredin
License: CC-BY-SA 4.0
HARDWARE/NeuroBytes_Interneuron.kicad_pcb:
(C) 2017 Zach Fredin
